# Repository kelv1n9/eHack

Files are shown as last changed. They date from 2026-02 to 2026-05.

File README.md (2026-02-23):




# 🚀 eHack

eHack

**eHack** is a versatile, all-in-one tool built on the **Raspberry Pi Pico**, designed for radio frequency analysis, penetration testing, and hardware research enthusiasts. The project integrates a wide array of tools for interacting with various wireless technologies, all housed in a compact form factor with a user-friendly OLED interface.

---

## 🛰️ Portable Module

The ***eHack Portable*** expands the reach of **eHack** beyond the main device.  
It is a lightweight RF companion that links wirelessly and can be fully managed through the interface of the primary unit.  
With it, you can launch experiments and carry out attacks remotely, bringing extra versatility to your toolkit.

More details about the portable module are available in its own repository: [eHack Portable](https://github.com/kelv1n9/eHack_Portable)

---

## 🤝 Contributor Wanted!

> For the **eHack** project, we are looking for a developer who can help with the software implementation for the **PN532 NFC module**. The goal is to add full tag reading, writing, and emulation capabilities.
>
> Your contribution to this feature would be highly appreciated! If you have the experience and a desire to contribute, please feel free to reach out.

| &nbsp; | Bands&nbsp;/&nbsp;Tech | What you can do |
|---|---|---|
| **Sub‑GHz (315 – 915 MHz)** | CC1101 | • Live spectrum and activity scan<br>• Capture & replay OOK/ASK packets <br>• **RAW** capture & replay<br>• **HF Monitor** (live log + quick resend)<br>• Gate / Barrier toolkit (capture, replay, brute‑force **CAME** & **NICE** codes)<br>• **Tesla** charge‑port opener<br>• Wide‑band noise jammer |
| **2.4 GHz** | NRF24L01+ | • Channel‑map spectrum viewer<br>• Jammers: All / Wi‑Fi / BT / BLE / USB / VIDEO / RC  <br> |
| **BLE Spam** | ESP32 C3 | • BLE Spam (iOS) |
| **Infra‑Red** | IR LED + receiver | • Capture & replay<br>• Built‑in brute‑force tables for TVs & projectors |
| **RFID / NFC** | rdm6300 + PN532 | • Read, emulate (125 kHz RFID)<br>• Basic NFC read/detect (Mifare Classic / Ultralight)<br>• Write mode placeholder (WIP) |
| **FM Radio** (***eHack Portable***) | Si4713 | • FM frequency control from main device (76–108 MHz)<br>• Remote input level indicator <br>|
| **Games** | — | • Falling Dots, Snake, Flappy Bird |
| **Quality‑of‑Life** | — | • OLED UI with 3‑button navigation<br> • Vibration feedback<br> • Battery monitor<br> • Auto‑dimming<br> • Connection Telemetry page<br> • Settings saved to EEPROM |

---
 ## 🎮 Controls

- `UP` / `DOWN` — menu navigation, frequency/slot selection, parameter adjustment
- `OK` (click) — confirm / start-stop action
- `OK` (hold) — back / exit current screen
- `UP + DOWN` (hold) — lock / unlock controls
- Hold `OK` during boot — toggle startup mode `eHack` / `eGames`

---

## 🔌 Pinout & Wiring

### Raspberry Pi Pico Pins Used

| Module | Pico pins | Note |
|---|---|---|
| I2C bus (OLED + PN532) | `SDA=GP0`, `SCL=GP1` | Shared I2C bus |
| NRF24L01+ (SPI) | `SCK=GP6`, `MOSI=GP7`, `MISO=GP4`, `CE=GP21`, `CSN=GP20` | 2.4 GHz module |
| CC1101 (SPI1) | `SCK=GP10`, `MOSI=GP11`, `MISO=GP12`, `CSN=GP13`, `GDO0=GP19` | Sub‑GHz module |
| Buttons | `UP=GP5`, `OK=GP8`, `DOWN=GP9` | Buttons to GND (`INPUT_PULLUP` in code) |
| IR | `TX=GP2`, `RX=GP3` | IR LED + IR receiver |
| RFID 125 kHz | `COIL=GP14`, `RDM6300_RX=GP15`, `RFID_POWER=GP27` | Power/enable controlled by GPIO |
| BLE trigger | `BLE_PIN=GP18` | Control pin for external BLE/ESP32 module |
| Vibro | `VIBRO=GP16` | Use transistor/driver stage |
| Battery monitor | `A3` | Battery voltage divider measurement |

---

## On‑Device Menu

```text
Main
├─ SubGHz
│   ├─ Air Scan
│   │   ├─ Spectrum
│   │   └─ Activity
│   ├─ Raw Scan
│   │   ├─ Capture
│   │   └─ Replay
│   ├─ Common
│   │   ├─ Capture
│   │   ├─ Replay
│   │   └─ Monitor
│   ├─ Barriers
│   │   ├─ Capture
│   │   ├─ Replay
│   │   └─ Brute (CAME / NICE)
│   ├─ Jammer
│   └─ Tesla
├─ 2.4 GHz
│   ├─ Spectrum
│   ├─ All Jam
│   ├─ Wi‑Fi Jam
│   ├─ BT Jam
│   ├─ BLE Jam
│   ├─ USB Jam
│   ├─ VIDEO Jam
│   ├─ RC Jam
│   └─ BLE Spam
├─ IR Tools
│   ├─ Capture
│   ├─ Replay
│   ├─ TV Brute
│   └─ Projector Brute
├─ FM Radio
├─ RFID
│   ├─ Read
│   ├─ Emulate
│   └─ Write
├─ Games
│   ├─ Falling Dots
│   ├─ Snake
│   └─ Flappy Bird
├─ Torch
├─ Connect
├─ Settings
└─ Telemetry
```
---

## Disclaimer 🚨

> **Educational & Research Use Only**  
> Use this hardware and software responsibly and **only on frequencies and systems you are legally allowed to transmit on**.  
> The author (**Elvin Gadirov**) accepts **no liability** for any damage, data loss, or legal consequences that may result from its use.  
> **All actions are at your own risk.** Always comply with local laws and regulations.

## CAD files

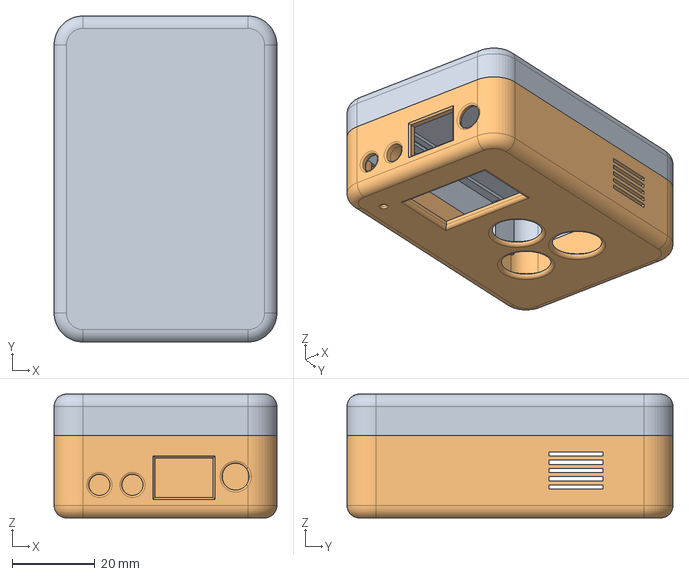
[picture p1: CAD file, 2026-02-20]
3D Model/Model_Main.FCStd
54.0 x 79.0 x 30.0 mm
Крышка
Корпус001

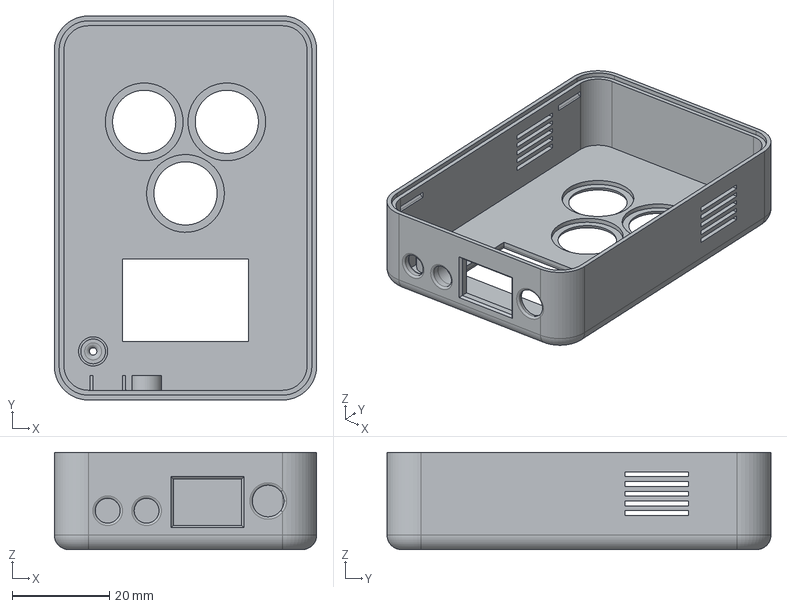
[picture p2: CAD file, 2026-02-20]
3D Model/eHack_Top.step
54.0 x 79.0 x 20.0 mm

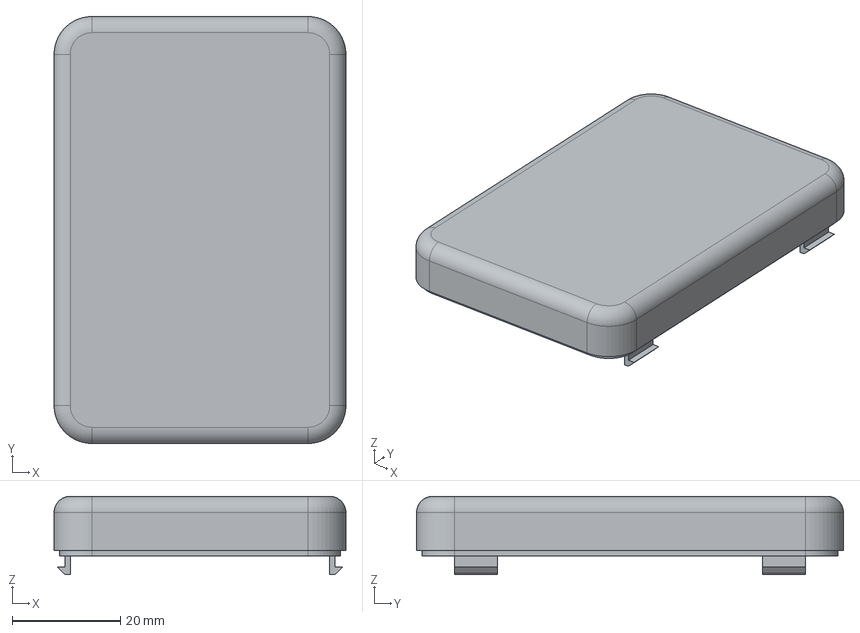
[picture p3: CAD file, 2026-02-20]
3D Model/eHack_Bottom.step
54.0 x 79.0 x 14.5 mm

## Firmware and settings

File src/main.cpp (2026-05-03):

#include "visualization.h"

void handleBatteryTasks();

void setup()
{
  EEPROM.begin(8192);

  // I2C
  Wire.setSDA(0);
  Wire.setSCL(1);
  Wire.setClock(400000);
  Wire.begin();

  // SPI
  SPI.setSCK(SCK_PIN_NRF);
  SPI.setTX(MOSI_PIN_NRF);
  SPI.setRX(MISO_PIN_NRF);
  SPI.begin();

  radio.begin();
  radio.powerDown();

  SPI1.setSCK(SCK_PIN_CC);
  SPI1.setTX(MOSI_PIN_CC);
  SPI1.setRX(MISO_PIN_CC);
  SPI1.begin();

  cc1101Init();

  loadStartMode();

  if (ok.read())
  {
    gamesOnlyMode = !gamesOnlyMode;
    saveStartMode();
  }
  if (gamesOnlyMode)
  {
    currentMenu = GAMES;
    APP_NAME = "eGames";
  }

  oled.init();
  oled.clear();
  resetBrightness();
  oled.update();
  ShowSplashScreen();

  delay(500);

  analogReadResolution(12);
  batVoltage = readBatteryVoltage();

  IrReceiver.begin(IR_RX, DISABLE_LED_FEEDBACK);
  IrSender.begin(IR_TX, DISABLE_LED_FEEDBACK, USE_DEFAULT_FEEDBACK_LED_PIN);
  IrReceiver.disableIRIn();

  pinMode(BTN_DOWN, INPUT_PULLUP);
  pinMode(BTN_OK, INPUT_PULLUP);
  pinMode(BTN_UP, INPUT_PULLUP);

  pinMode(RFID_COIL_PIN, OUTPUT);
  digitalWrite(RFID_COIL_PIN, LOW);

  pinMode(BLE_PIN, OUTPUT);
  digitalWrite(BLE_PIN, LOW);

  pinMode(RFID_POWER_PIN, OUTPUT);
  digitalWrite(RFID_POWER_PIN, HIGH);

  pinMode(VIBRO, OUTPUT);

  findLastUsedSlotRA();
  findLastUsedSlotIR();
  findLastUsedSlotRFID();
  findLastUsedSlotBarrier();

  loadSettings();
  loadAllScores();
  loadStartConnection();

  if (startConnection)
  {
    communication.setMasterMode();
    communication.init();
    connectionInited = true;
  }

  for (uint8_t i = 0; i < RSSI_BUFFER_SIZE; i++)
  {
    rssiBuffer[i] = -100;
  }

  vibro(255, 30);

#ifdef DEBUG_eHack
  Serial.begin(9600);
#endif

  // eraseAllEEPROM();
}

void setup1()
{
}

void loop1()
{
  switch (currentMenu)
  {
  /*============================= 433 MHz Protocol =================================*/
  /********************************** SCANNING **************************************/
  case HF_SCAN:
  {
    if (!initialized)
    {
      pinMode(GD0_PIN_CC, INPUT);
      mySwitch.enableReceive(GD0_PIN_CC);
      cc1101.SetRx(raFrequencies[currentFreqIndex]);

      if (successfullyConnected)
      {
        outgoingDataLen = communication.buildPacket(COMMAND_HF_SCAN, &currentFreqIndex, 1, outgoingData);
        communication.sendPacket(outgoingData, outgoingDataLen);
      }

      initialized = true;
    }

    if (checkFreqButtons())
    {
      cc1101.SetRx(raFrequencies[currentFreqIndex]);
      if (successfullyConnected)
      {
        outgoingDataLen = communication.buildPacket(COMMAND_HF_SCAN, &currentFreqIndex, 1, outgoingData);
        communication.sendPacket(outgoingData, outgoingDataLen);
      }
    }

    if (mySwitch.available())
    {
      // Check if the signal is valid
      if (mySwitch.getReceivedBitlength() < 10)
      {
        mySwitch.resetAvailable();
        break;
      }

      signalCaptured_433MHZ = true;

      currentRssi = cc1101.getRssi();
      capturedCode = mySwitch.getReceivedValue();
      capturedLength = mySwitch.getReceivedBitlength();
      capturedProtocol = mySwitch.getReceivedProtocol();
      capturedDelay = mySwitch.getReceivedDelay();

      addHFMonitorEntry(currentFreqIndex, capturedCode, currentRssi, capturedProtocol, false, true, true, capturedLength);

      SimpleRAData data;
      data.code = capturedCode;
      data.length = capturedLength;
      data.protocol = capturedProtocol;
      data.delay = capturedDelay;

      strncpy(data.name, "NEW", NAME_MAX_LEN);
      data.name[NAME_MAX_LEN] = '\0';

      vibro(255, 200, 3, 80);

      // Check for duplicates
      if (isDuplicateRA(data))
      {
        mySwitch.resetAvailable();
        break;
      }

      if (settings.saveRA)
      {
        writeRAData(lastUsedSlotRA, data);
      }

      lastUsedSlotRA = (lastUsedSlotRA + 1) % MAX_RA_SIGNALS;
      mySwitch.resetAvailable();
    }
    break;
  }
  /********************************** ATTACK **************************************/
  case HF_REPLAY:
  {
    static uint32_t attackTimer = 0;

    if (RANameEdit || RAMenu)
    {
      return;
    }

    if (!initialized)
    {
      pinMode(GD0_PIN_CC, OUTPUT);
      mySwitch.enableTransmit(GD0_PIN_CC);
      cc1101.SetTx(raFrequencies[currentFreqIndex]);

      if (successfullyConnected)
      {
        outgoingDataLen = communication.buildPacket(COMMAND_HF_REPLAY, &currentFreqIndex, 1, outgoingData);
        communication.sendPacket(outgoingData, outgoingDataLen);
      }

      commandSent = false;
      initialized = true;
    }

    if (!locked && !attackIsActive && (up.click() || up.step()))
    {
      if (selectedSlotRA == 0)
        selectedSlotRA = MAX_RA_SIGNALS - 1;
      else
        selectedSlotRA--;
      vibro(255, 20);
    }

    if (!locked && !attackIsActive && (down.click() || down.step()))
    {
      selectedSlotRA = (selectedSlotRA + 1) % MAX_RA_SIGNALS;
      vibro(255, 20);
    }

    mySwitch.setProtocol(capturedProtocol);

    if (attackIsActive)
    {
      if (checkFreqButtons())
      {
        cc1101.SetTx(raFrequencies[currentFreqIndex]);
        if (successfullyConnected)
        {
          outgoingDataLen = communication.buildPacket(COMMAND_HF_REPLAY, &currentFreqIndex, 1, outgoingData);
          communication.sendPacket(outgoingData, outgoingDataLen);
        }
      }

      if (millis() - attackTimer >= 1000 && !successfullyConnected)
      {
        mySwitch.send(capturedCode, capturedLength);
        attackTimer = millis();
      }
      else if (successfullyConnected && !commandSent)
      {
        mySwitch.send(capturedCode, capturedLength);
        commandSent = true;
      }
    }

    break;
  }
  /******************************* BARRIER SCAN **********************************/
  case HF_BARRIER_SCAN:
  {
    if (!initialized)
    {
      pinMode(GD0_PIN_CC, INPUT);
      attachInterrupt(digitalPinToInterrupt(GD0_PIN_CC), captureBarrierCode, CHANGE);
      cc1101.SetRx(raFrequencies[currentFreqIndex]);

      if (successfullyConnected)
      {
        outgoingDataLen = communication.buildPacket(COMMAND_HF_BARRIER_SCAN, &currentFreqIndex, 1, outgoingData);
        communication.sendPacket(outgoingData, outgoingDataLen);
      }

      initialized = true;
    }

    if (checkFreqButtons())
    {
      cc1101.SetRx(raFrequencies[currentFreqIndex]);
      if (successfullyConnected)
      {
        outgoingDataLen = communication.buildPacket(COMMAND_HF_BARRIER_SCAN, &currentFreqIndex, 1, outgoingData);
        communication.sendPacket(outgoingData, outgoingDataLen);
      }
    }

    if (barrierCaptured)
    {
      signalCaptured_433MHZ = true;
      currentRssi = cc1101.getRssi();

      SimpleBarrierData data;
      data.codeMain = barrierCodeMain;
      data.codeAdd = barrierCodeAdd;
      data.protocol = barrierProtocol;

      vibro(255, 200, 3, 80);

      // Check for duplicates
      if (isDuplicateBarrier(data))
      {
        barrierCaptured = false;
        break;
      }

      if (settings.saveRA)
      {
        writeBarrierData(lastUsedSlotBarrier, data);
      }

      lastUsedSlotBarrier = (lastUsedSlotBarrier + 1) % MAX_BARRIER_SIGNALS;

      barrierCaptured = false;
    }

    break;
  }
  /********************************** BARRIER REPLAY **************************************/
  case HF_BARRIER_REPLAY:
  {
    static uint32_t attackTimer = 0;

    if (!initialized)
    {
      ok.reset();
      pinMode(GD0_PIN_CC, OUTPUT);
      cc1101.SetTx(raFrequencies[currentFreqIndex]);

      if (successfullyConnected)
      {
        outgoingDataLen = communication.buildPacket(COMMAND_HF_BARRIER_REPLAY, &currentFreqIndex, 1, outgoingData);
        communication.sendPacket(outgoingData, outgoingDataLen);
      }

      commandSent = false;
      initialized = true;
    }

    if (!locked && !attackIsActive && (up.click() || up.step()))
    {
      if (selectedSlotBarrier == 0)
        selectedSlotBarrier = MAX_BARRIER_SIGNALS - 1;
      else
        selectedSlotBarrier--;
      vibro(255, 20);
    }

    if (!locked && !attackIsActive && (down.click() || down.step()))
    {
      selectedSlotBarrier = (selectedSlotBarrier + 1) % MAX_BARRIER_SIGNALS;
      vibro(255, 20);
    }

    SimpleBarrierData data = readBarrierData(selectedSlotBarrier);
    barrierCodeMain = data.codeMain;
    barrierCodeAdd = data.codeAdd;
    barrierProtocol = data.protocol;

    if (attackIsActive)
    {
      if (checkFreqButtons())
      {
        cc1101.SetTx(raFrequencies[currentFreqIndex]);
        if (successfullyConnected)
        {
          outgoingDataLen = communication.buildPacket(COMMAND_HF_BARRIER_REPLAY, &currentFreqIndex, 1, outgoingData);
          communication.sendPacket(outgoingData, outgoingDataLen);
        }
      }

      if (millis() - attackTimer >= 1000 && !successfullyConnected)
      {
        if (barrierProtocol == 0)
        {
          sendANMotors(barrierCodeMain, barrierCodeAdd);
        }
        else if (barrierProtocol == 1)
        {
          sendNice(barrierCodeMain);
        }
        else if (barrierProtocol == 2)
        {
          sendCame(barrierCodeMain);
        }
        attackTimer = millis();
      }
      else if (successfullyConnected && !commandSent)
      {
        if (barrierProtocol == 0)
        {
          sendANMotors(barrierCodeMain, barrierCodeAdd);
        }
        else if (barrierProtocol == 1)
        {
          sendNice(barrierCodeMain);
        }
        else if (barrierProtocol == 2)
        {
          sendCame(barrierCodeMain);
        }
        commandSent = true;
      }
    }

    break;
  }
  /********************************** BRUTE CAME **************************************/
  case HF_BARRIER_BRUTE_CAME:
  {
    static uint32_t lastSendTime = 0;

    if (!initialized)
    {
      ok.reset();
      if (!successfullyConnected)
      {
        pinMode(GD0_PIN_CC, OUTPUT);
        cc1101.SetTx(raFrequencies[currentFreqIndex]);
      }
      initialized = true;
    }

    switch (bruteState)
    {
    case BRUTE_IDLE:
    {
      if (!locked && ok.click())
      {
        if (successfullyConnected)
        {
          outgoingDataLen = communication.buildPacket(COMMAND_HF_BARRIER_BRUTE_CAME, &currentFreqIndex, 1, outgoingData);
          communication.sendPacket(outgoingData, outgoingDataLen);
        }

        bruteState = BRUTE_RUNNING;
        barrierBruteIndex = 4095;
        lastSendTime = millis();

        vibro(255, 50);
      }
      break;
    }

    case BRUTE_RUNNING:
    {
      if (!locked && ok.click())
      {
        bruteState = BRUTE_PAUSED;
        vibro(255, 50);
        break;
      }

      if (millis() - lastSendTime > 50)
      {
        lastSendTime = millis();

        if (barrierBruteIndex >= 0)
        {
          if (!successfullyConnected)
            sendCame(barrierBruteIndex);
          barrierBruteIndex--;
        }
        if (barrierBruteIndex < 0)
        {
          bruteState = BRUTE_IDLE;
          vibro(255, 50);
        }
      }
      break;
    }
    case BRUTE_PAUSED:
    {
      if (!locked && (up.click() || up.step()))
      {
        if (barrierBruteIndex == 4095)
          barrierBruteIndex = 0;
        else
          barrierBruteIndex++;
        vibro(255, 20);
      }

      if (!locked && (down.click() || down.step()))
      {
        if (barrierBruteIndex == 0)
          barrierBruteIndex = 4095;
        else
          barrierBruteIndex--;
        vibro(255, 20);
      }

      if (!locked && ok.click())
      {
        sendCame(barrierBruteIndex);
        vibro(255, 50);
      }
      break;
    }
    }
    break;
  }
  /********************************** BRUTE NICE **************************************/
  case HF_BARRIER_BRUTE_NICE:
  {
    static uint32_t lastSendTime = 0;

    if (!initialized)
    {
      ok.reset();
      if (!successfullyConnected)
      {
        pinMode(GD0_PIN_CC, OUTPUT);
        cc1101.SetTx(raFrequencies[currentFreqIndex]);
      }
      initialized = true;
    }

    switch (bruteState)
    {
    case BRUTE_IDLE:
    {
      if (!locked && ok.click())
      {
        if (successfullyConnected)
        {
          outgoingDataLen = communication.buildPacket(COMMAND_HF_BARRIER_BRUTE_NICE, &currentFreqIndex, 1, outgoingData);
          communication.sendPacket(outgoingData, outgoingDataLen);
        }

        bruteState = BRUTE_RUNNING;
        barrierBruteIndex = 4095;
        lastSendTime = millis();

        vibro(255, 50);
      }
      break;
    }

    case BRUTE_RUNNING:
    {
      if (!locked && ok.click())
      {
        bruteState = BRUTE_PAUSED;
        vibro(255, 50);
        break;
      }

      if (millis() - lastSendTime > 50)
      {
        lastSendTime = millis();

        if (barrierBruteIndex >= 0)
        {
          if (!successfullyConnected)
            sendNice(barrierBruteIndex);
          barrierBruteIndex--;
        }
        if (barrierBruteIndex < 0)
        {
          bruteState = BRUTE_IDLE;
          vibro(255, 50);
        }
      }
      break;
    }
    case BRUTE_PAUSED:
    {
      if (!locked && (up.click() || up.step()))
      {
        if (barrierBruteIndex == 4095)
          barrierBruteIndex = 0;
        else
          barrierBruteIndex++;
        vibro(255, 20);
      }
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
void loop()
{
  up.tick();
  down.tick();
  ok.tick();

  oled.clear();

  if (up.hold() && down.hold() && currentMenu != DOTS_GAME && currentMenu != SNAKE_GAME && currentMenu != FLAPPY_GAME && currentMenu != HF_REPLAY && currentMenu != HF_RAW_REPLAY && currentMenu != HF_BARRIER_REPLAY && currentMenu != IR_REPLAY && currentMenu != RFID_EMULATE)
  {
    locked = !locked;

    if (locked)
    {
      vibro(255, 30, 2);
    }
    else
    {
      vibro(255, 30);
    }
  }

  if (locked)
  {
    showLock();
  }

  // if (isPortableInited)
  // {
  //   showPortableInited();
  // }

  if (isCharging)
  {
    showCharging();
  }

  if (!locked && (up.press() || ok.press() || down.press()))
  {
    if (isScreenDimmed || isScreenOff)
    {
      up.skipEvents();
      ok.skipEvents();
      down.skipEvents();
    }
    resetBrightness();
    resetScreenOff();
  }

  if (!locked && ok.hold())
  {
    bool isSimpleMenuExit = false;
    MenuState lastMenu = currentMenu;

    if (currentMenu == MAIN_MENU)
    {
      vibro(255, 50, 3, 100);
      return;
    }

    if (gamesOnlyMode)
    {
      currentMenu = GAMES;
    }
    else
    {
      currentMenu = parentMenu;
      parentMenu = grandParentMenu;
      grandParentMenu = MAIN_MENU;
    }

    switch (lastMenu)
    {
    case SETTINGS:
    {
      saveSettings();
      isSimpleMenuExit = true;
      break;
    }
    case CONNECTION:
    {
      initialized = false;
      isSimpleMenuExit = true;
      saveStartConnection();
      break;
    }
    case TELEMETRY:
    {
      telemetryReset();
      initialized = false;
      isSimpleMenuExit = true;
      break;
    }
    case GAMES:
    {
      if (gamesOnlyMode)
      {
        vibro(255, 50, 3, 100);
        return;
      }
    }
    case UHF_MENU:
    case IR_MENU:
    case RFID_MENU:
    case HF_MENU:
    case HF_AIR_MENU:
    case HF_RAW_MENU:
    case HF_COMMON_MENU:
    case HF_BARRIER_MENU:
    case HF_BARRIER_BRUTE_MENU:
    case TORCH:
    {
      vibro(255, 50);
      break;
    }
    case IR_SCAN:
    {
      signalCaptured_IR = false;
    }
    case IR_REPLAY:
    case IR_BRUTE_TV:
    case IR_BRUTE_PROJECTOR:
    {
      bruteState = BRUTE_IDLE;
      IrReceiver.disableIRIn();
      isSimpleMenuExit = true;
      break;
    }
    case HF_JAMMER:
    case HF_TESLA:
    {
      digitalWrite(GD0_PIN_CC, LOW);
      isSimpleMenuExit = true;
      break;
    }
    case HF_CALIBRATE_MENU:
    {
      isSimpleMenuExit = true;
      break;
    }
    case HF_CALIBRATE:
    {
      cc1101Init();
      isSimpleMenuExit = true;
      break;
    }
    case HF_SPECTRUM:
    case HF_ACTIVITY:
    {
      initialized = false;
      // isPortableInited = false;
      if (successfullyConnected)
      {
        sendStopCommandToSlave(6);
      }
      if (settings.activeScan)
      {
        mySwitch.disableReceive();
        mySwitch.disableTransmit();
      }
      vibro(255, 50);
      break;
    }
    case HF_RAW_CAPTURE:
    {
      detachInterrupt(digitalPinToInterrupt(GD0_PIN_CC));
      rawCapturing = false;
      initialized = false;
      vibro(255, 50);
      break;
    }
    case HF_RAW_REPLAY:
    {
      rawReplaying = false;
      rawReplayRequested = false;
      rawRecorded = false;
      RAMenu = false;
      RANameEdit = false;
      RANamePos = 0;
      initialized = false;
      vibro(255, 50);
      break;
    }
    case HF_REPLAY:
    {
      attackIsActive = false;
    }
    case HF_MONITOR:
    {
    }
    case HF_SCAN:
    {
      mySwitch.disableReceive();
      mySwitch.disableTransmit();
      signalCaptured_433MHZ = false;
      isSimpleMenuExit = true;
      break;
    }
    case HF_BARRIER_SCAN:
    {
      detachInterrupt(GD0_PIN_CC);
    }
    case HF_BARRIER_BRUTE_CAME:
    case HF_BARRIER_BRUTE_NICE:
    case HF_BARRIER_REPLAY:
    {
      isSimpleMenuExit = true;
      attackIsActive = false;
      bruteState = BRUTE_IDLE;
      break;
    }
    case UHF_SPECTRUM:
    {
      stopRadioAttack();
      communication.setMasterMode();
      communication.init();
      connectionInited = true;
      initialized = false;
      if (successfullyConnected)
      {
        sendStopCommandToSlave(6);
      }
      // isPortableInited = false;
      vibro(255, 50);
      break;
    }
    case UHF_ALL_JAMMER:
    case UHF_WIFI_JAMMER:
    case UHF_BT_JAMMER:
    case UHF_BLE_JAMMER:
    case UHF_USB_JAMMER:
    case UHF_VIDEO_JAMMER:
    case UHF_RC_JAMMER:
    {
      stopRadioAttack();
      communication.setMasterMode();
      communication.init();
      connectionInited = true;
      initialized = false;
      // isPortableInited = false;
      if (successfullyConnected)
      {
        sendStopCommandToSlave(6);
      }
      vibro(255, 50);
      break;
    }
    case UHF_BLE_SPAM:
    {
      digitalWrite(BLE_PIN, LOW);
      isSimpleMenuExit = true;
      break;
    }
    case RFID_EMULATE:
    case RFID_WRITE:
    case RFID_SCAN:
    {
      attackIsActive = false;
      nfc.setRFField(0, 0);
      nfc.powerDownMode();
      rdm6300.end();
      digitalWrite(RFID_COIL_PIN, LOW);
      digitalWrite(RFID_POWER_PIN, HIGH);
      initialized = false;
      vibro(255, 50);
      break;
    }
    case DOTS_GAME:
    case SNAKE_GAME:
    case FLAPPY_GAME:
    {
      vibro(255, 50);
      break;
    }
    case FM_RADIO:
    {
      isSimpleMenuExit = true;
      break;
    }
    }

    if (isSimpleMenuExit)
    {
      initialized = false;
      if (successfullyConnected)
      {
        outgoingDataLen = communication.buildPacket(COMMAND_IDLE, 0, 0, outgoingData);
        communication.sendPacket(outgoingData, outgoingDataLen);
      }
      // isPortableInited = false;
      vibro(255, 50);
      return;
    }
  }

  switch (currentMenu)
  {
  case MAIN_MENU:
  {
    if (gamesOnlyMode)
    {
      currentMenu = GAMES;
      break;
    }

    uint8_t visibleMenuCount = successfullyConnected ? mainMenuCount : mainMenuCount - 1;
    if (MAINmenuIndex >= visibleMenuCount)
      MAINmenuIndex = visibleMenuCount - 1;
    menuButtons(MAINmenuIndex, visibleMenuCount);
    drawMenu(mainMenuItems, visibleMenuCount, MAINmenuIndex);

    if (!locked && ok.click())
    {
      grandParentMenu = parentMenu;
      parentMenu = currentMenu;
      currentMenu = static_cast<MenuState>(MAINmenuIndex + 1);
      vibro(255, 50);
    }
    break;
  }
  case HF_MENU:
  {
    menuButtons(HFmenuIndex, hfMenuCount);
    drawMenu(hfMenuItems, hfMenuCount, HFmenuIndex);

    if (!locked && ok.click())
    {
      ok.reset();
      grandParentMenu = parentMenu;
      parentMenu = currentMenu;
      currentMenu = static_cast<MenuState>(HF_AIR_MENU + HFmenuIndex);
      vibro(255, 50);
    }
    break;
  }
  case HF_CALIBRATE_MENU:
  {
    menuButtons(calibBandIndex, 4);
    drawMenu(calibBandItems, 4, calibBandIndex);

    if (!locked && ok.click())
    {
      ok.reset();
      grandParentMenu = parentMenu;
      parentMenu = currentMenu;
      calibStep = 0;
      calibMeasured = calibFreqLow[calibBandIndex];
      initialized = false;
      currentMenu = HF_CALIBRATE;
      vibro(255, 50);
    }
    break;
  }
  case HF_CALIBRATE:
  {
    if (calibStep < 2)
    {
      if (!locked && up.click())
        calibMeasured += 0.010f;
      if (!locked && up.step())
        calibMeasured += 0.100f;
      if (!locked && down.click())
        calibMeasured -= 0.010f;
      if (!locked && down.step())
        calibMeasured -= 0.100f;

      if (!locked && ok.click())
      {
        ok.reset();
        float targetFreq = (calibStep == 0) ? calibFreqLow[calibBandIndex] : calibFreqHigh[calibBandIndex];
        if (calibStep == 0)
        {
          calibClbLow = calculateFSCTRL0(targetFreq, calibMeasured);
          calibMeasured = calibFreqHigh[calibBandIndex];
          calibStep = 1;
          initialized = false;
        }
        else
        {
          calibClbHigh = calculateFSCTRL0(targetFreq, calibMeasured);
          calibrationData.clb[calibBandIndex][0] = calibClbLow;
          calibrationData.clb[calibBandIndex][1] = calibClbHigh;
          saveCalibration();
          calibStep = 2;
          calibSavedTimer = millis();
        }
        vibro(255, 50);
      }
    }

    if (calibStep == 2 && millis() - calibSavedTimer > 2000)
    {
      cc1101Init();
      currentMenu = parentMenu;
      initialized = false;
      return;
    }

    DrawCalibrate();
    break;
  }
  case IR_MENU:
  {
    menuButtons(IRmenuIndex, irMenuCount);
    drawMenu(irMenuItems, irMenuCount, IRmenuIndex);
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

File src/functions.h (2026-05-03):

#define EB_DEB_TIME 15
#define EB_HOLD_TIME 300
#define NFC_INTERFACE_I2C

// #define DEBUG_eHack
#define VERSION "v5.5.1"

#ifdef DEBUG_eHack
#define DBG(...)                \
  do                            \
  {                             \
    Serial.printf(__VA_ARGS__); \
  } while (0)
#else
#define DBG(...) \
  do             \
  {              \
  } while (0)
#endif

#include <Wire.h>
#include <SPI.h>
#include <EEPROM.h>

#include <PN532_I2C.h>
#include <PN532_I2C.cpp>
#include <PN532.h>
#include <GyverOLED.h>
#include <EncButton.h>
#include <RCSwitch.h>
#include <IRremote.hpp>
#include "signal_data.h"
#include "hardware/adc.h"
#include "RF24.h"
#include <rdm6300.h>
#include "CC1101.h"
#include "DataTransmission.h"

#ifdef DEBUG_eHack
#define APP_VERSION VERSION " DEBUG"
#else
#define APP_VERSION VERSION
#endif
const char *APP_NAME = "eHack";

#define BLE_PIN 18

#define VIBRO 16

#define BTN_DOWN 9
#define BTN_OK 8
#define BTN_UP 5

#define IR_TX 2
#define IR_RX 3

Button up(BTN_UP);
Button ok(BTN_OK);
Button down(BTN_DOWN);

volatile bool initialized = false;
volatile bool locked = false;

uint8_t mainMenuCount = 10;
uint8_t hfMenuCount = 7;
uint8_t irMenuCount = 4;
uint8_t rawMenuCount = 2;
uint8_t uhfMenuCount = 9;
uint8_t RFIDMenuCount = 3;
uint8_t gamesMenuCount = 3;
uint8_t barrierMenuCount = 3;
uint8_t RAsignalMenuCount = 2;
uint8_t hfCommonMenuCount = 3;
uint8_t barrierBruteMenuCount = 2;

uint8_t MAINmenuIndex = 0;
uint8_t HFmenuIndex = 0;
uint8_t IRmenuIndex = 0;
uint8_t rawMenuIndex = 0;
uint8_t uhfMenuIndex = 0;
uint8_t RFIDMenuIndex = 0;
uint8_t gamesMenuIndex = 0;
uint8_t barrierMenuIndex = 0;
uint8_t RAsignalMenuIndex = 0;
uint8_t HFCommonMenuIndex = 0;
uint8_t barrierBruteMenuIndex = 0;

/* ================= Battery ================== */
#define BATTERY_COEFFICIENT 0.9611905
#define R1 200000 // 200k
#define R2 100000 // 100k
#define BATTERY_RESISTANCE_COEFFICIENT (1 + R1 / R2)
#define V_REF 3.3

#define BATTERY_CHECK_INTERVAL 10000
#define BATTERY_MIN_VOLTAGE 3.2
#define BATTERY_MAX_VOLTAGE 4.2
#define BATTERY_READ_ITERATIONS 10

#define HISTORY_SIZE 5
#define CHARGE_THRESHOLD 0.015
#define CHARGING_ANIM_INTERVAL 500
#define CHARGING_ANIM_FRAMES 4

float batVoltage;
float voltageHistory[HISTORY_SIZE] = {0};
uint32_t batteryTimer;
uint32_t remotebatteryTimer;
uint8_t historyIndex = 0;
bool isCharging = false;
bool historyValid = false;

uint32_t batteryDisplayToggleTimer = 0;
uint32_t batteryCheckTimer = 0;

uint8_t chargingAnimFrame = 0;
uint32_t chargingAnimTimer = 0;

bool showLocalVoltage = true;
float remoteVoltage;
/* ==================== OLED ================== */
#define SCREEN_WIDTH 128
#define SCREEN_HEIGHT 64
#define MIN_BRIGHTNESS 5
#define MAX_BRIGHTNESS 255
#define BRIGHTNESS_TIME 30000
#define SCREENOFF_TIME 60000
#define SPECTRUM_TOP_LIMIT 10
#define SCREEN_BOTTOM 63

GyverOLED<SSD1306_128x64, OLED_BUFFER> oled;

bool peaksDynamic = true;
uint32_t brightnessTimer;

bool isScreenOff;
bool isScreenDimmed;
uint32_t offTimer;

/* ==================== Tesla ================== */
#define pulseWidth 400     // µs
#define messageDistance 23 // ms
#define transmissions 5

/* =================== SubGHz MHz ================== */
#define SCK_PIN_CC 10
#define MOSI_PIN_CC 11
#define MISO_PIN_CC 12
#define CSN_PIN_CC 13
#define GD0_PIN_CC 19

#define RSSI_WINDOW_MS 100
#define RSSI_STEP_MS 50
#define RSSI_BUFFER_SIZE 90

#define NAME_MAX_LEN 10

#define MAX_HF_MONITOR_SIGNALS 20
#define HF_MONITOR_VISIBLE_LINES 6

int currentRssi = -100;
uint8_t currentFreqIndex = 1;
uint8_t currentScanFreq = 0;
const float raFrequencies[] = {315.0, 433.92, 868.35, 915.0};
const uint8_t raFreqCount = sizeof(raFrequencies) / sizeof(raFrequencies[0]);
float rssiMaxPeak[raFreqCount] = {-100, -100, -100, -100};
float rssiAbsoluteMax[raFreqCount] = {-100, -100, -100, -100};

uint8_t rssiIndex = 0;
int rssiBuffer[RSSI_BUFFER_SIZE];

RCSwitch mySwitch = RCSwitch();

struct SimpleRAData
{
  uint32_t code;
  uint16_t length;
  uint16_t protocol;
  uint16_t delay;
  char name[NAME_MAX_LEN + 1];
};

uint8_t lastUsedSlotRA = 0;
uint8_t selectedSlotRA = 0;

uint32_t capturedCode;
uint16_t capturedLength;
uint16_t capturedProtocol;
uint16_t capturedDelay;

bool attackIsActive = false;
bool signalCaptured_433MHZ = false;
uint32_t signalIndicatorUntil = 0;
uint32_t rawSendIndicatorUntil = 0;

struct HFMonitorEntry
{
  uint16_t freqMHz100;
  uint32_t code;
  int8_t rssi;
  uint8_t protocol;
  uint8_t bitLength;
  bool isRemote;
  bool codeValid;
  bool protocolValid;
};

HFMonitorEntry hfMonitorEntries[MAX_HF_MONITOR_SIGNALS];
bool hfMonitorSendRequested = false;
bool hfMonitorAutoFollow = true;
uint8_t hfMonitorHead = 0;
uint8_t hfMonitorCount = 0;
uint8_t hfMonitorTopIndex = 0;
uint8_t hfMonitorCursorIndex = 0;
uint32_t hfMonitorRemoteLogMs = 0;

const char PROGMEM *hfReplayMenuItems[] = {
    "Label",
    "Remove",
};

uint8_t RANamePos;
uint8_t RAMenuIndex;
bool RAMenu;
bool RANameEdit;

const char PROGMEM nameChars[] = "ABCDEFGHIJKLMNOPQRSTUVWXYZ0123456789_ ";
char slotName[NAME_MAX_LEN + 1];

/* ================== SubGHz Calibration ================== */

struct CalibrationData
{
  uint8_t clb[4][2];
} calibrationData;

const float calibFreqLow[4] = {300.0f, 378.0f, 779.0f, 900.0f};
const float calibFreqHigh[4] = {348.0f, 464.0f, 899.0f, 928.0f};
uint8_t calibBandIndex = 0;
uint8_t calibStep = 0;
uint8_t calibClbLow = 0;
uint8_t calibClbHigh = 0;
uint32_t calibTxTimer = 0;
uint32_t calibSavedTimer = 0;
float calibMeasured = 0.0f;

/* ================ RAW Signal =================== */
#define RAW_SIGNAL_MAX_SAMPLES 1024
#define MAX_RAW_SAVE_SAMPLES 512

struct RawSignalSlot
{
  uint16_t sampleCount;
  uint8_t freqIndex;
  char name[NAME_MAX_LEN + 1];
  uint16_t samples[MAX_RAW_SAVE_SAMPLES];
};

uint8_t selectedSlotRAW = 0;
uint8_t nextRawSlotToWrite = 0;
uint16_t rawRecordedCount = 0;

bool rawRecorded = false;
bool rawReplaying = false;
volatile uint16_t rawSignalBuffer[RAW_SIGNAL_MAX_SAMPLES];
volatile uint16_t rawSignalCount = 0;
volatile uint32_t rawLastEdgeMicros = 0;
volatile bool rawFirstEdge = true;
volatile bool rawCapturing = false;
volatile bool rawOverflow = false;
volatile bool rawReplayRequested = false;

void rawSignalISR()
{
  uint32_t now = micros();
  if (rawFirstEdge)
  {
    rawFirstEdge = false;
    rawLastEdgeMicros = now;
    return;
  }

  uint32_t duration = now - rawLastEdgeMicros;
  rawLastEdgeMicros = now;

  if (duration > 65535)
    duration = 65535;
  if (duration < 10)
    return;

  if (rawCapturing)
  {
    rawSignalBuffer[rawSignalCount % RAW_SIGNAL_MAX_SAMPLES] = (uint16_t)duration;
    if (rawSignalCount < 0xFFFE)
      rawSignalCount++;
  }
}

void rawStartCapture()
{
  noInterrupts();
  rawSignalCount = 0;
  rawFirstEdge = true;
  rawOverflow = false;
  rawCapturing = true;
  rawRecorded = false;
  interrupts();
}
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

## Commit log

2025-05-31 Bug fixes, minor changes
    [main.cpp, visualization.h]
2025-06-04 Fixed bug with RSSI for barriers signal
    [main.cpp]
2025-06-05 Updated game module, RSSI Spectrum. Decreased noise from PN532
    [functions.h, main.cpp, visualization.h]
2025-06-05 Added new ir commands
    [power_commands.csv]
2025-06-05 Updated commands for IR (Projector)
    [power_commands.csv]
2025-06-05 Calibrated RSSI, improved sensitivity
2025-06-06 Fixed bug with RF RX/TX
    [functions.h, main.cpp]
2025-06-08 Added an icon while a charging process
2025-06-09 Added new library for data transmission between main and portable devices
2025-06-14 Added communication between eHack and portable module. Changed some basic functions. Minor bug fix.
    To do:
    1. Recieve battery voltage from portable module.
    2. Add the support of the data transmission in Activity and Spectrum modes.
    [functions.h, main.cpp, visualization.h]
2025-06-15 Fixed bug with CC1101 communication process.
    [functions.h, main.cpp, visualization.h]
2025-06-15 Added new channels for WIFI, BLE, BT, USB, Video, RC jamming.
    [functions.h, main.cpp, signal_data.h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]
2025-06-16 Added new protocols from Flipper Zero Firmware: Nice, Came, CameTwee, KeeLoq, NiceFlo, Princeton
    [functions.h, main.cpp, visualization.h]
2025-06-17 Added new RF protocols from Flipper Zero Firmware: NeroSketch, Hormann, NeroRadio, GateTX, Linear, LinearD3, MegaCode, Holtek, Chamberlain, PowerSmart, Marantec, Bett, DoitRand, PhoenixV2. And some m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
    [functions.h, main.cpp, visualization.h]
2025-06-20 Fixed issues with connection
    [functions.h, main.cpp]
2025-06-20 Battery upd
2025-06-21 Fixed bugs with the chnging of frequency on the portable module
    [functions.h, main.cpp]
2025-06-21 Improved a battery status update and a data transmission between devices
2025-06-22 Fixed issue with channels
    [functions.h, main.cpp, signal_data.h]
2025-06-22 Fixed issue with the frequency changing
    [main.cpp]
2025-06-22 Updated 2.4 GHz Jammer
    [main.cpp]
2025-06-23 Bug fix and added report of starting regime
    [functions.h, main.cpp, visualization.h]
2025-06-25 Improved stability of connection and working
    [main.cpp, visualization.h]
2025-06-26 Fixed bug with CC1101 (was not receiving signal)
    [functions.h, main.cpp]
2025-06-27 Removed protocols due to RC-Switch
2025-06-28 Improved stability and added debugging
    [functions.h, main.cpp]
2025-06-28 Improved stability of connection with simple connection method. Fixed bugs with connection.
    [functions.h, main.cpp]
2025-06-28 Added vibration response on connecting and disconnecting the portable module.
    [functions.h, main.cpp]
2025-06-29 Added support for exiting HF_ACTIVITY mode on a portable device without powering off the device
2025-06-29 Returned an old channel swapping method for UHF Jamming
    [main.cpp]
2025-06-29 Added support for exiting UHF Jamming mode on a portable device without powering off the device
    [functions.h, main.cpp]
2025-06-29 Bug fix and added method to change HF_ACTIVITY frequency on portable device
    [main.cpp]
2025-06-30 Added communication attempts number and showing remote battery voltage after connection
2025-07-01 Came, Nice, AN-Motors code receiving and sending function restored
2025-07-01 Fixed bug with CAME/NICE BruteForce
    [functions.h, main.cpp, visualization.h]
2025-07-16 Release 4.1.0 Added the option to specify a specific SPI bus for CC1101. Separated SPI buses (SPI, SPI1) for nrf24l01 and CC1101.
2025-07-26 Release 4.1.2 Added a function to automatically connect to a portable device when the device is started. Minor improvements for stability of communication between devices.
    [functions.h, main.cpp]
2025-07-26 Release 4.1.3 Added torch mode, automatic switching between internal and external receivers upon disconnection/connection, and various minor improvements
2025-08-25 Beta 5.1.0
    - A scrollable settings menu has been implemented.
    - An option to enable/disable vibration has been added.
    - An option to enable/disable signal decoding during RSSI detection has been added.
    - An error with incorrect EEPROM address calculation has been fixed.
    [functions.h, main.cpp, visualization.h]
2025-09-11 FM triangle cursor was replaced with step-based rectangle
    [functions.h, main.cpp, visualization.h]
2025-11-29 Added games-only mode and screen off. Minor bug fixes.
    [functions.h, main.cpp, visualization.h]
2025-11-30 Added a test version of adding names for saved HF signals. Bug fixes
    [functions.h, main.cpp, visualization.h]
2025-12-02 Minor fixes. Version 5.2.1
    [functions.h, main.cpp, visualization.h]
2025-12-02 Bug fixes in FM Radio module.
    [functions.h, main.cpp, visualization.h]
2026-02-03 CC1101 Calibration
2026-02-05 Add RFID_POWER_PIN definition and update setup for power management
2026-02-05 Update RFID_POWER_PIN definition and adjust power management logic in setup
2026-02-05 Add battery display option and reset settings functionality
    [functions.h, main.cpp, visualization.h]
2026-02-13 Update minimum battery voltage threshold to improve battery monitoring
2026-02-15 Update charge threshold and enhance charging animation display
2026-02-17 Add charging animation parameters and improve menu visibility handling
2026-02-20 Added 3D Models
    [Model_Main.FCStd, eHack_Bottom.step, eHack_Top.step]
2026-02-23 Add EEPROM slot management functions and update command handling in main loop
2026-04-19 Display current radio channel on connection status
2026-04-28 Add SubGHz band calibration feature
2026-04-28 Update version to v5.5.0 and add calibration data initialization in setup
2026-04-28 Updated calibration function
2026-04-30 Fix RFID storage and scanner re-entry bugs
    [functions.h, main.cpp]

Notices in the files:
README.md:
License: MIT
